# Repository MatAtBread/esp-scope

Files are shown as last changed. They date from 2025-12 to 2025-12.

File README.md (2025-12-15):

# ESP-Scope

## Overview
ESP-Scope is a web-based oscilloscope built using the ESP-IDF framework. It allows users to visualize analog signals in real-time through a web browser. The project leverages the ESP32's ADC capabilities and serves a web interface for signal visualization. It contains complete source code and 3D design for a case for the Seeed XIAO ESP32C6.

This project was written in part to test AI code generators and see if they're any good. Much of the code was written by Google Antigravity using Gemini 3, with refinements, hints and tips and overall design specified by a human. The whole app was up and running a few hours and finished, including 3D design in a weekend.

esp-scope

## Features
- Real-time signal visualization on a web browser.
- Adjustable sample rate (1-83333 Hz) and attenuation.
- Crosshair functionality for precise measurements.
- Adjustable trigger level.
- Test signal generation.
- Reset functionality to clear settings and reload the interface.
- Power off from the browser.

## Getting Started

### Prerequisites
- ESP32 development board.
- [ESP-IDF](https://github.com/espressif/esp-idf) installed and configured.
- USB cable to connect the ESP32 to your computer.
- A web browser (e.g., Chrome, Firefox).

### Downloading the Project
1. Clone the repository:
   ```bash
   git clone https://github.com/MatAtBread/esp-scope.git
   ```
2. Navigate to the project directory:
   ```bash
   cd esp-scope
   ```

### Building and Flashing

If you have the esp-idf VSCode extension, just click on the flame to build, flash & monitor. Use the config settings for "espScope" to specify GPIO pins for the LED & "AP-Mode" button, and if necessary a board-specific setup file (one is provided for the Seeed Studio XIAO ESP32C6 to enable the internal ceramic antenna).

1. Set up the ESP-IDF environment:
   ```bash
   . $IDF_PATH/export.sh
   ```
2. Configure the project:
   ```bash
   idf.py menuconfig
   ```
3. Build the project:
   ```bash
   idf.py build
   ```
4. Flash the firmware to the ESP32:
   ```bash
   idf.py -p [PORT] flash
   ```
   Replace `[PORT]` with the serial port of your ESP32 (e.g., `/dev/ttyUSB0` or `COM3`).
5. Monitor the serial output:
   ```bash
   idf.py monitor
   ```

### Using the esp-scope

If your DHCP server supports it (most seem to), the app sets its hostname and you can just navigate to http://esp-scope (you may have/need a default domain extension)

1. After flashing, ESP-SCOPE will start as a WiFi access point. Connect to it to access the UI.
2. If desired, click the "WiFi" button and set your SSID & WiFi password. The device will reboot and join your network. Pressing and holding the GPIO "AP-Mode" button will erase the WiFi credentials and return to Access Point mode.
3. Open a web browser and navigate to "http://esp-scope" (you may have/need a default domain extension).
4. Use the web interface to:
   - Adjust settings like sample rate, attenuation & the test signal frequency.
   - Visualize signals in real-time.
   - Reset the interface using the "Reset" button.
   - Re-configure the WiFi using the "WiFi" button.
   - Power off the device

The LED indicates one of four conditions:
* Continuously lit: waiting to attach to a wifi network or starting the wireless AP
* Equal 1 second flash: in AP mode - connect to the "ESP-Scope" access point
* Slow, brief flashes: connected to the WiFi SSID set in the web UI
* Rapid, brief flashes: sending data to an active client

### Attaching hardware

The displayed signal is sampled from ADC0. The test signal is output on D1. The default GPIOs for the LED and "AP-Mode" button are 15 and 9 respectively (hard-wired on an Seeed XIAO ESP32C6 to the yellow LED and "Boot" button).

## 3D design

The 3D design is a two part case with space for a AA-battery (Li-poly 3.7v, which can connect directly to a Seeed XIAO ESP device) clips and holes for the USB-C connector and "ground", "signal" and "test" connections using standard 2.54mm pitch, easily cut from jumpers and soldered directly to the Seeed XIAO. The 3D design was done using Fusion 360 and printed on a Bambu Labs A1 Mini in 30 minutes.

I recommend putting the "Signal" connection in the middle, and never connecting the outer-most pins (ground and test) to avoid shorting the test signal to ground and (probably) frying the esp32. The middle (signal) pin can be connected to either of its neigbours and you'll see either the ground or the test signal.

esp-scope

## License
This project is licensed under the MIT License. See the LICENSE file for details.

## Acknowledgments
- Built using the ESP-IDF framework by Espressif Systems.
- Gemini 3.

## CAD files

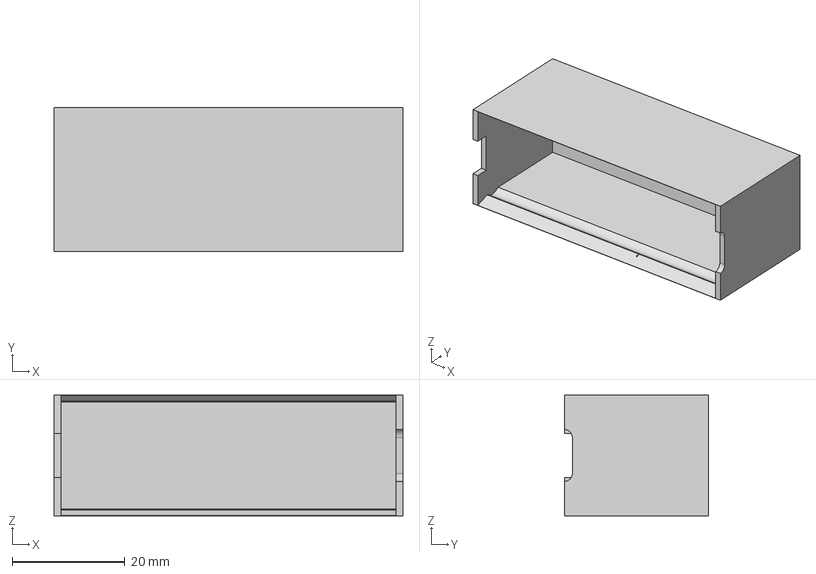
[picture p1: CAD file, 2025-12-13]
3D/Base.step
61.9 x 25.5 x 21.4 mm

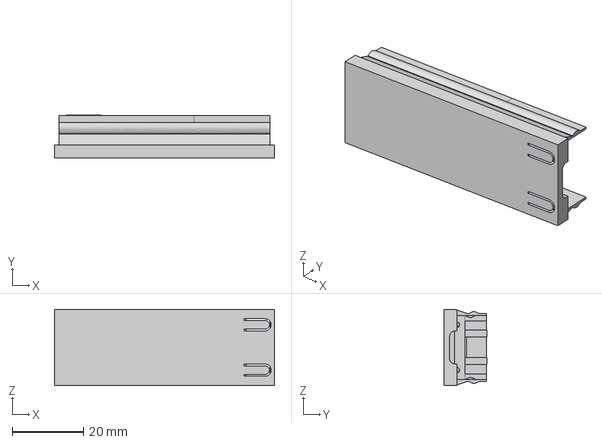
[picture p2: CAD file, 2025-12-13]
3D/Lid.step
61.9 x 12.2 x 21.4 mm

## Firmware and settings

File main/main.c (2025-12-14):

#include <inttypes.h>
#include <stdbool.h>
#include <stdint.h>
#include <stdio.h>
#include <string.h>

#include "cJSON.h"
#include "driver/gpio.h"
#include "driver/ledc.h"
#include "esp_adc/adc_continuous.h"
#include "esp_event.h"
#include "esp_http_server.h"
#include "esp_log.h"
#include "esp_sleep.h"
#include "esp_system.h"
#include "esp_wifi.h"
#include "esp_timer.h"
#include "freertos/FreeRTOS.h"
#include "freertos/event_groups.h"
#include "freertos/task.h"
#include "wifi_manager.h"
#include "nvs_flash.h"

// Tag for logging
static const char* TAG = "ESP-SCOPE";

// Embedded index.html
extern const uint8_t index_html_start[] asm("_binary_index_html_start");
extern const uint8_t index_html_end[] asm("_binary_index_html_end");
extern const uint8_t index_js_start[] asm("_binary_index_js_start");
extern const uint8_t index_js_end[] asm("_binary_index_js_end");

// Forward declarations
static void start_webserver(void);

// ADC Configuration
#define ADC_UNIT ADC_UNIT_1
#define ADC_UNIT ADC_UNIT_1
#define ADC_CONV_MODE ADC_CONV_SINGLE_UNIT_1
#define ADC_ATTEN ADC_ATTEN_DB_11
#define ADC_BIT_WIDTH ADC_BITWIDTH_12

#define ADC_OUTPUT_TYPE ADC_DIGI_OUTPUT_FORMAT_TYPE2
#define ADC_GET_DATA(p_data) ((p_data)->type2.data)

/*
 * Web Server Configuration
 */
static httpd_handle_t s_server = NULL;
static bool is_ap = false;
#define ADC_READ_LEN 4096

static adc_continuous_handle_t adc_handle = NULL;

// Single client support for simplicity, or use a list for multiple
static int s_ws_client_fd = -1;

// Global configuration state
static volatile bool s_reconfig_needed = false;
static uint32_t s_sample_rate = 10000;
static adc_atten_t s_atten = ADC_ATTEN_DB_12;
static adc_bitwidth_t s_bit_width = ADC_BIT_WIDTH;
static uint16_t s_test_hz = 100;

// Forward declarations
static void continuous_adc_init(adc_channel_t* channel, uint8_t channel_num,
                                adc_continuous_handle_t* out_handle);
static esp_err_t ws_handler(httpd_req_t* req);

// Helper to calculate optimal buffer size (approx 50ms latency, max 4096, aligned to 4)
static uint32_t get_optimal_buffer_size(uint32_t sample_rate) {
  uint32_t bytes_per_sec = sample_rate * sizeof(adc_digi_output_data_t);
  uint32_t target_size = bytes_per_sec / 50;  // 20ms (50Hz)

  // Clamp to min/max
  if (target_size < 128) target_size = 128;
  if (target_size > ADC_READ_LEN) target_size = ADC_READ_LEN;

  // Align to 4 bytes
  return (target_size + 3) & ~3;
}

/*
 * Task to read from ADC Continuous driver
 */
static void adc_read_task(void* arg) {
  esp_err_t ret;
  uint32_t ret_num = 0;
  uint8_t result[ADC_READ_LEN] = {0};
  memset(result, 0xcc, ADC_READ_LEN);

  // ADC Init (Moved from app_main)
  // TODO: Make this configurable or find a good default pin.
  // For ESP32C6 ADC1 Channel 0 is usually GPIO 0. Let's use Channel 0 for now.
  adc_channel_t channel[1] = {ADC_CHANNEL_0};
  continuous_adc_init(channel, sizeof(channel) / sizeof(adc_channel_t),
                      &adc_handle);
  ESP_ERROR_CHECK(adc_continuous_start(adc_handle));

  while (1) {
    if (s_reconfig_needed) {
      ESP_LOGI(TAG, "Reconfiguring ADC...");
      if (adc_handle) {
        ESP_LOGI(TAG, "Stopping ADC...");
        ret = adc_continuous_stop(adc_handle);
        if (ret != ESP_OK) {
          ESP_LOGE(TAG, "adc_continuous_stop failed: %s", esp_err_to_name(ret));
        }
        ESP_LOGI(TAG, "Deinitializing ADC...");
        ret = adc_continuous_deinit(adc_handle);
        if (ret != ESP_OK) {
          ESP_LOGE(TAG, "adc_continuous_deinit failed: %s",
                   esp_err_to_name(ret));
        }
        adc_handle = NULL;
      }

      // Small delay to ensure hardware state clears
      vTaskDelay(pdMS_TO_TICKS(20));

      // Update global defaults for next init
      // Note: In a robust app, we should pass these to init function
      // For now, we rely on the global s_sample_rate etc being read by init
      adc_channel_t channel[1] = {ADC_CHANNEL_0};
      continuous_adc_init(channel, 1, &adc_handle);

      ESP_LOGI(TAG, "Starting ADC...");
      ESP_ERROR_CHECK(adc_continuous_start(adc_handle));
      ESP_LOGI(TAG, "ADC Reconfigured and Restarted");
      s_reconfig_needed = false;
    }

    ret = adc_continuous_read(adc_handle, result, get_optimal_buffer_size(s_sample_rate), &ret_num, 0);
    if (ret == ESP_OK) {
      // ESP_LOGI(TAG, "ret is %x, ret_num is %"PRIu32" bytes", ret, ret_num);

      // OPTIMIZED BATCH SENDING
      // We have `ret_num` bytes of data in `result`.
      // It contains `adc_digi_output_data_t` structs (4 bytes each).
      // We want to extract just the data (12-16 bits) to save bandwidth?
      // The original code was: `uint16_t val = (uint16_t)data;` and sent that.
      // So we have 1/2 the size.

      if (s_ws_client_fd != -1) {
        // Allocate a small temp buffer on stack or static to avoid malloc in loop
        // ret_num is up to ADC_READ_LEN (1024). 1024 / 4 = 256 samples.
        // 256 * 2 bytes = 512 bytes output. Stack safe.
        uint16_t out_buf[ADC_READ_LEN / sizeof(adc_digi_output_data_t)];
        int out_idx = 0;

        for (int i = 0; i < ret_num; i += sizeof(adc_digi_output_data_t)) {
          adc_digi_output_data_t* p = (adc_digi_output_data_t*)&result[i];
          uint32_t val = ADC_GET_DATA(p);
          out_buf[out_idx++] = (uint16_t)val;
        }

        if (out_idx > 0) {
          httpd_ws_frame_t ws_frame = {
              .final = true,
              .fragmented = false,
              .type = HTTPD_WS_TYPE_BINARY,
              .payload = (uint8_t*)out_buf,
              .len = out_idx * sizeof(uint16_t)};

          // Non-blocking send (best effort)
          esp_err_t ret_ws = httpd_ws_send_frame_async(s_server, s_ws_client_fd, &ws_frame);
          if (ret_ws != ESP_OK) {
            ESP_LOGW(TAG, "dropped: %s", esp_err_to_name(ret_ws));

            // Invalidate FD if it's no longer valid (client disconnected)
            if (ret_ws == ESP_ERR_INVALID_ARG || ret_ws == ESP_FAIL) {
              s_ws_client_fd = -1;
            }
          }
        }
      }

      /**
       * Yield check
       */
      taskYIELD(); /* Explicit yield to let WiFi stack run if needed, though send_async should handle it */
    } else if (ret == ESP_ERR_TIMEOUT) {
      // We try to read `ADC_READ_LEN` until API returns timeout, which means
      // there's no available data
      vTaskDelay(pdMS_TO_TICKS(10));
    }
  }
}

static void continuous_adc_init(adc_channel_t* channel, uint8_t channel_num,
                                adc_continuous_handle_t* out_handle) {
  uint32_t frame_size = get_optimal_buffer_size(s_sample_rate);
  ESP_LOGI(TAG, "Dynamic Buffer Size: %lu bytes", frame_size);

  adc_continuous_handle_cfg_t adc_config = {
      .max_store_buf_size = 16384,
      .conv_frame_size = frame_size,
  };
  ESP_ERROR_CHECK(adc_continuous_new_handle(&adc_config, out_handle));

  // Update the global read length used by the task (hacky but simple for now)
  // Ideally return it, but our init function signature is fixed.
  // We can rely on get_optimal_buffer_size(s_sample_rate) being consistent.

  adc_continuous_config_t dig_cfg = {
      .sample_freq_hz = s_sample_rate,
      .conv_mode = ADC_CONV_MODE,
      .format = ADC_OUTPUT_TYPE,
  };

  adc_digi_pattern_config_t adc_pattern[SOC_ADC_PATT_LEN_MAX] = {0};
  dig_cfg.pattern_num = channel_num;

  for (int i = 0; i < channel_num; i++) {
    adc_pattern[i].atten = s_atten;
    adc_pattern[i].channel = channel[i] & 0x7;
    adc_pattern[i].unit = ADC_UNIT;
    adc_pattern[i].bit_width = s_bit_width;

    ESP_LOGI(TAG, "adc_pattern[%d].atten is :%" PRIx8, i, adc_pattern[i].atten);
    ESP_LOGI(TAG, "adc_pattern[%d].channel is :%" PRIx8, i,
             adc_pattern[i].channel);
    ESP_LOGI(TAG, "adc_pattern[%d].unit is :%" PRIx8, i, adc_pattern[i].unit);
  }
  dig_cfg.adc_pattern = adc_pattern;
  ESP_ERROR_CHECK(adc_continuous_config(*out_handle, &dig_cfg));
}
static bool ledc_inited = false;
static void start_test_signal(uint32_t hz) {
  if (ledc_inited) {
    ESP_LOGI(TAG, "De-init test signal");
    gpio_reset_pin(GPIO_NUM_1);

    // Stop the PWM signal on channel 0
    ledc_stop(LEDC_LOW_SPEED_MODE, LEDC_CHANNEL_0, 0);

    // Reset the timer configuration
    ledc_timer_rst(LEDC_LOW_SPEED_MODE, LEDC_TIMER_0);

    // (Optional) Uninstall fade functionality if used
    ledc_fade_func_uninstall();
  }
  ESP_LOGI(TAG, "Starting test signal at %u Hz", hz);
  ledc_timer_config_t ledc_timer = {
      .speed_mode = LEDC_LOW_SPEED_MODE,
      .duty_resolution = LEDC_TIMER_14_BIT,
      .timer_num = LEDC_TIMER_0,
      .freq_hz = hz,
      .clk_cfg = LEDC_AUTO_CLK};
  ledc_channel_config_t ledc_channel = {
      .gpio_num = 1,  // GPIO data pin 1
      .speed_mode = LEDC_LOW_SPEED_MODE,
      .channel = LEDC_CHANNEL_0,
      .timer_sel = LEDC_TIMER_0,
      .duty = 1 << (ledc_timer.duty_resolution - 1),  // 512, // 50% duty cycle (1024 / 2 for 10-bit resolution)
      .hpoint = 0};

  // Initialize the PWM
  ledc_timer_config(&ledc_timer);
  ledc_channel_config(&ledc_channel);
  // Start the PWM signal
  ledc_set_duty(ledc_channel.speed_mode, ledc_channel.channel, ledc_channel.duty);  // 50% duty cycle
  ledc_update_duty(ledc_channel.speed_mode, ledc_channel.channel);
  ledc_inited = true;
}

static void show_status_led() {
  #ifdef CONFIG_BSP_CONFIG_GPIO
  gpio_config_t rst_conf = {
      .pin_bit_mask = (1ULL << CONFIG_BSP_CONFIG_GPIO),
      .mode = GPIO_MODE_INPUT,
      .pull_up_en = GPIO_PULLUP_ENABLE,
      .pull_down_en = GPIO_PULLDOWN_DISABLE,
      .intr_type = GPIO_INTR_DISABLE
  };
  gpio_config(&rst_conf);
  #endif

  int64_t reset_pressed_time = 0;
  while (true) {
    int64_t now = esp_timer_get_time() / 1000;
#ifdef CONFIG_LED_BUILTIN
    if (is_ap) {
      vTaskDelay(pdMS_TO_TICKS(500));
      gpio_set_level(CONFIG_LED_BUILTIN, 1);
      vTaskDelay(pdMS_TO_TICKS(500));
    } else {
      if (is_connected()) {
        vTaskDelay(pdMS_TO_TICKS(100));
        gpio_set_level(CONFIG_LED_BUILTIN, 1);
      }
      vTaskDelay(pdMS_TO_TICKS(s_ws_client_fd == -1 ? 900 : 200));
    }
    gpio_set_level(CONFIG_LED_BUILTIN, 0);
#else
    vTaskDelay(pdMS_TO_TICKS(1000));
#endif

// Check Reset Pin
#ifdef CONFIG_BSP_CONFIG_GPIO
    if (!is_ap && gpio_get_level(CONFIG_BSP_CONFIG_GPIO) == 0) {
      if (now - reset_pressed_time > 1000) {
        ESP_LOGW(TAG, "Reset to WiFi-AP mode triggered via GPIO %d", CONFIG_BSP_CONFIG_GPIO);
        wifi_manager_erase_config();
        esp_restart();
      } else {
        reset_pressed_time = now;
      }
    } else {
      reset_pressed_time = 0;
    }
#endif
  }
}

void app_main(void) {
  // Initialize NVS
  esp_err_t ret = nvs_flash_init();
  if (ret == ESP_ERR_NVS_NO_FREE_PAGES ||
      ret == ESP_ERR_NVS_NEW_VERSION_FOUND) {
    ESP_ERROR_CHECK(nvs_flash_erase());
    ret = nvs_flash_init();
  }
  ESP_ERROR_CHECK(ret);

#ifdef CONFIG_LED_BUILTIN
  gpio_config_t led_io_conf = {
      .pin_bit_mask = (1ULL << CONFIG_LED_BUILTIN),
      .mode = GPIO_MODE_OUTPUT,
      .pull_up_en = GPIO_PULLUP_DISABLE,
      .pull_down_en = GPIO_PULLDOWN_DISABLE,
      .intr_type = GPIO_INTR_DISABLE};
  gpio_config(&led_io_conf);
  gpio_set_level(CONFIG_LED_BUILTIN, 0);
#endif

#ifdef CONFIG_BOARD_SPECIFIC_INIT
#include CONFIG_BOARD_SPECIFIC_INIT
#endif

  is_ap = wifi_manager_init_wifi();

  start_test_signal(100);
  xTaskCreate(adc_read_task, "adc_read_task", 8192 + ADC_READ_LEN, NULL, 5, NULL);

  // Wait for WiFi connection (Not strict blocking anymore, manager handles it)
  // But let's keep it to print status
  // Note: s_wifi_event_group is local to this file, we removed it in place of manager's.
  // Proper way: expose event group from manager or just dont block here.
  // For now, let's just proceed. The webserver will start and wait for connections.

  start_webserver();
  show_status_led();
}


/*
 * WebSocket Handler
 */
static esp_err_t ws_handler(httpd_req_t* req) {
  if (req->method == HTTP_GET) {
    // Handshake
    return ESP_OK;
  }

  httpd_ws_frame_t ws_pkt;
  uint8_t* buf = NULL;
  memset(&ws_pkt, 0, sizeof(httpd_ws_frame_t));
  ws_pkt.type = HTTPD_WS_TYPE_TEXT;

  // Get frame len
  esp_err_t ret = httpd_ws_recv_frame(req, &ws_pkt, 0);
  if (ret != ESP_OK)
    return ret;

  if (ws_pkt.len) {
    buf = calloc(1, ws_pkt.len + 1);
    if (buf == NULL)
      return ESP_ERR_NO_MEM;
    ws_pkt.payload = buf;
    ret = httpd_ws_recv_frame(req, &ws_pkt, ws_pkt.len);
    if (ret != ESP_OK) {
      free(buf);
      return ret;
    }

    // Check for "hello"
    if (ws_pkt.type == HTTPD_WS_TYPE_TEXT &&
        strcmp((char*)ws_pkt.payload, "hello") == 0) {
      ESP_LOGI(TAG, "New WS client connected, fd=%d", httpd_req_to_sockfd(req));
      s_ws_client_fd = httpd_req_to_sockfd(req);
    }
    free(buf);
  }
  return ESP_OK;
}

/*
 * Control Params Handler (POST /params)
 */
static esp_err_t params_handler(httpd_req_t* req) {
  char buf[256];
  int ret, remaining = req->content_len;
  if (remaining >= sizeof(buf)) {
    httpd_resp_send_500(req);
    return ESP_FAIL;
  }

  ret = httpd_req_recv(req, buf, remaining);
  if (ret <= 0)
    return ESP_FAIL;
  buf[ret] = '\0';

  cJSON* root = cJSON_Parse(buf);
  if (root) {
    cJSON* sample_rate = cJSON_GetObjectItem(root, "sample_rate");
    if (sample_rate && s_sample_rate != sample_rate->valueint) {
      s_reconfig_needed = true;
      s_sample_rate = sample_rate->valueint;
    }
    cJSON* atten = cJSON_GetObjectItem(root, "atten");
    if (atten && s_atten != (adc_atten_t)atten->valueint) {
      s_reconfig_needed = true;
      s_atten = (adc_atten_t)atten->valueint;
    }
    cJSON* bit_width = cJSON_GetObjectItem(root, "bit_width");
    if (bit_width && s_bit_width != (adc_bitwidth_t)bit_width->valueint) {
      s_reconfig_needed = true;
      s_bit_width = (adc_bitwidth_t)bit_width->valueint;
    }
    cJSON* test_hz = cJSON_GetObjectItem(root, "test_hz");
    if (test_hz) {
      if (s_test_hz != (adc_bitwidth_t)test_hz->valueint) {
        s_test_hz = (adc_bitwidth_t)test_hz->valueint;
        start_test_signal(s_test_hz);
      }
    }

    ESP_LOGI(TAG, "Config Request: Rate=%lu, Atten=%d, Width=%d, TestHz=%u, s_reconfig_needed=%d", s_sample_rate,
             s_atten, s_bit_width, s_test_hz,
             s_reconfig_needed);

    cJSON_Delete(root);
  }

  httpd_resp_send(req, "OK", 2);
  return ESP_OK;
}

static const httpd_uri_t uri_ws = {.uri = "/signal",
                                   .method = HTTP_GET,
                                   .handler = ws_handler,
                                   .user_ctx = NULL,
                                   .is_websocket = true};

static const httpd_uri_t uri_params = {.uri = "/params",
                                       .method = HTTP_POST,
                                       .handler = params_handler,
                                       .user_ctx = NULL};

/* Handler for serving index.html */
static esp_err_t index_handler(httpd_req_t* req) {
  httpd_resp_set_type(req, "text/html");
  httpd_resp_set_hdr(req, "Content-Type", "text/html; charset=utf-8");
  uint32_t len = index_html_end - index_html_start;
  // Workaround for some build systems adding null byte
  while (len && index_js_start[len - 1] == 0) len--;
  httpd_resp_send(req, (const char*)index_html_start, len);
  return ESP_OK;
}

static const httpd_uri_t uri_index = {
    .uri = "/", .method = HTTP_GET, .handler = index_handler, .user_ctx = NULL};

/* Handler for serving index.js */
static esp_err_t index_js_handler(httpd_req_t* req) {
  httpd_resp_set_type(req, "text/javascript");
  httpd_resp_set_hdr(req, "Content-Type", "text/javascript; charset=utf-8");
  uint32_t len = index_js_end - index_js_start;
  // Workaround for some build systems adding null byte
  while (len && index_js_start[len - 1] == 0) len--;
  httpd_resp_send(req, (const char*)index_js_start, len);
  return ESP_OK;
}

static const httpd_uri_t uri_index_js = {
    .uri = "/index.js", .method = HTTP_GET, .handler = index_js_handler, .user_ctx = NULL};

static const char *bye = "<head></head><body style='font-family: -apple-system, BlinkMacSystemFont, &quot;Segoe UI&quot;, Roboto, Helvetica, Arial, sans-serif;\n  background: #1a1a1a;\n  color: #e0e0e0;'><h1>Bye!</h1>Press \"reset\" on your esp-scope to start it up again</body>";

static esp_err_t power_handler(httpd_req_t* req) {
  httpd_resp_set_type(req, "text/html");
  httpd_resp_set_hdr(req, "Content-Type", "text/html; charset=utf-8");
  httpd_resp_send(req, bye, HTTPD_RESP_USE_STRLEN);

  // delay to ensure network is flushed
  vTaskDelay(pdMS_TO_TICKS(200));

  esp_deep_sleep_start();
  return ESP_OK;
}

static const httpd_uri_t uri_power = {
    .uri = "/poweroff", .method = HTTP_GET, .handler = power_handler, .user_ctx = NULL};

/* Error handler for 404 - Redirects to captive portal */
static esp_err_t http_404_error_handler(httpd_req_t *req, httpd_err_code_t err)
{
    /* Set status 302 Redirect */
    httpd_resp_set_status(req, "302 Found");
    httpd_resp_set_hdr(req, "Location", "/");
    httpd_resp_send(req, NULL, 0); // No body needed
    return ESP_OK;
}

static void start_webserver(void) {
  httpd_config_t config = HTTPD_DEFAULT_CONFIG();
  config.lru_purge_enable = true;

  ESP_LOGI(TAG, "Starting webserver on port: '%d'", config.server_port);
  if (httpd_start(&s_server, &config) == ESP_OK) {
    ESP_LOGI(TAG, "Registering URI handlers");
    httpd_register_uri_handler(s_server, &uri_index);
    httpd_register_uri_handler(s_server, &uri_index_js);
    httpd_register_uri_handler(s_server, &uri_ws);
    httpd_register_uri_handler(s_server, &uri_params);

    // Register WiFi Manager endpoints
    wifi_manager_register_uri(s_server);
    httpd_register_uri_handler(s_server, &uri_power);

    // Register 404 handler for Captive Portal redirection
    httpd_register_err_handler(s_server, HTTPD_404_NOT_FOUND, http_404_error_handler);
  } else {
    ESP_LOGI(TAG, "Error starting server!");
  }
}

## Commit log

2025-12-13 Add poweroff function & status LED. Include 3D files for Seeed XIAO
    [Base.step, Lid.step]
2025-12-13 Stop /poweroff reloading. Update 3D files
    [Base.step, Lid.step]
2025-12-14 Add soft-ap mode, remove wifi config.
    Device defaukts to soft-ap mode. User can use the "WIFI" button to set wifi credentials. Pressing "boot" for 1 second resets to soft-ap mode.
    Re-work UI to fill screen.
    [main.c]
2025-12-15 Add zoom on scroll-wheel. Tidy up index.js
